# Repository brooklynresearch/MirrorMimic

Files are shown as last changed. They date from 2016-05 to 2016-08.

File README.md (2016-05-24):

# Mirror Mimic

This repository is for communicating and controlling robotic systems.
Currently set up for controlling torso, neck, and upper arm articulation.

## Software
1. [Arduino 1.6.8](https://www.arduino.cc)
2. [Teensyduino](https://www.pjrc.com/teensy/teensyduino.html)

### Software Libraries/Dependencies
1. DynamixelController - Controlling Dynamixels with the Teensy (Based on Arbotix Library)
2. [OSC - OSC communication with the Teensy](https://github.com/CNMAT/OSC)

## Hardware
1. [Microcontroller - Teensy 3.2](https://www.pjrc.com/store/teensy32.html)
2. [Servo - Dynamixel MX-64T](http://www.trossenrobotics.com/p/mx-64t-dynamixel-robot-actuator.aspx)
3. [Stepper Motor NEMA23 - 23L310S-LW8](http://www.anaheimautomation.com/products/stepper/stepper-motor-item.php?sID=20&pt=i&tID=75&cID=19)
4. [Stepper Driver - MBC25081TB](http://www.anaheimautomation.com/products/stepper/stepper-driver-item.php?sID=56&serID=4&pt=i&tID=87&cID=20)

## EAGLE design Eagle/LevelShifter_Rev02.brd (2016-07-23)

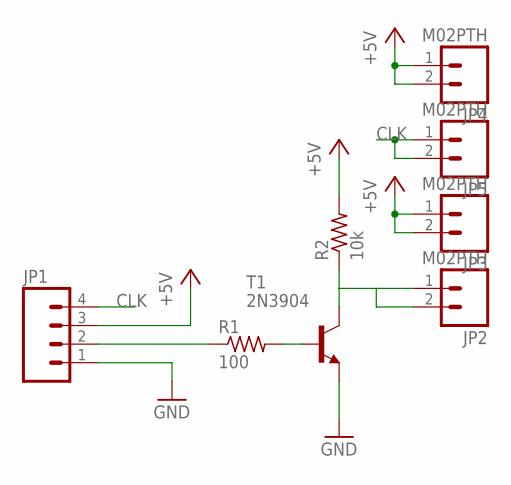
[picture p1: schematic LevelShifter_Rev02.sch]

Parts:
JP1: M04SCREW; SCREWTERMINAL-3.5MM-4
JP2, JP3, JP4, JP5: M02PTH; 1X02
R1: 100; 0204/7
R2: 10k; 0204/7
T1: 2N3904; TO92

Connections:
+5V: JP1.3, JP3.1, JP3.2, JP4.1, JP4.2, R2.2
CLK: JP1.4, JP5.1, JP5.2
GND: JP1.1, T1.3 (E)
unnamed: R1.2, T1.2 (B)
unnamed: JP2.1, JP2.2, R2.1, T1.1 (C)
unnamed: JP1.2, R1.1

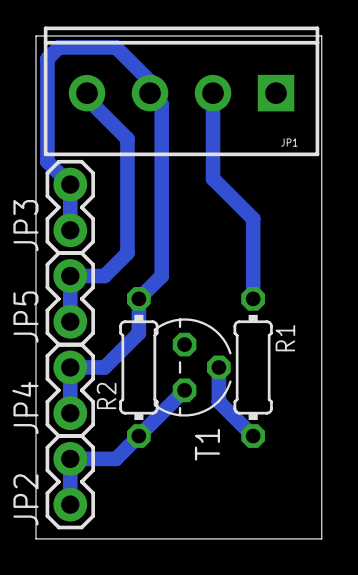
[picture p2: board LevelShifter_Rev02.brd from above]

Board: 2 copper layers, 15.9 x 27.9 mm, 8 parts (0 on the bottom side), 6 nets.

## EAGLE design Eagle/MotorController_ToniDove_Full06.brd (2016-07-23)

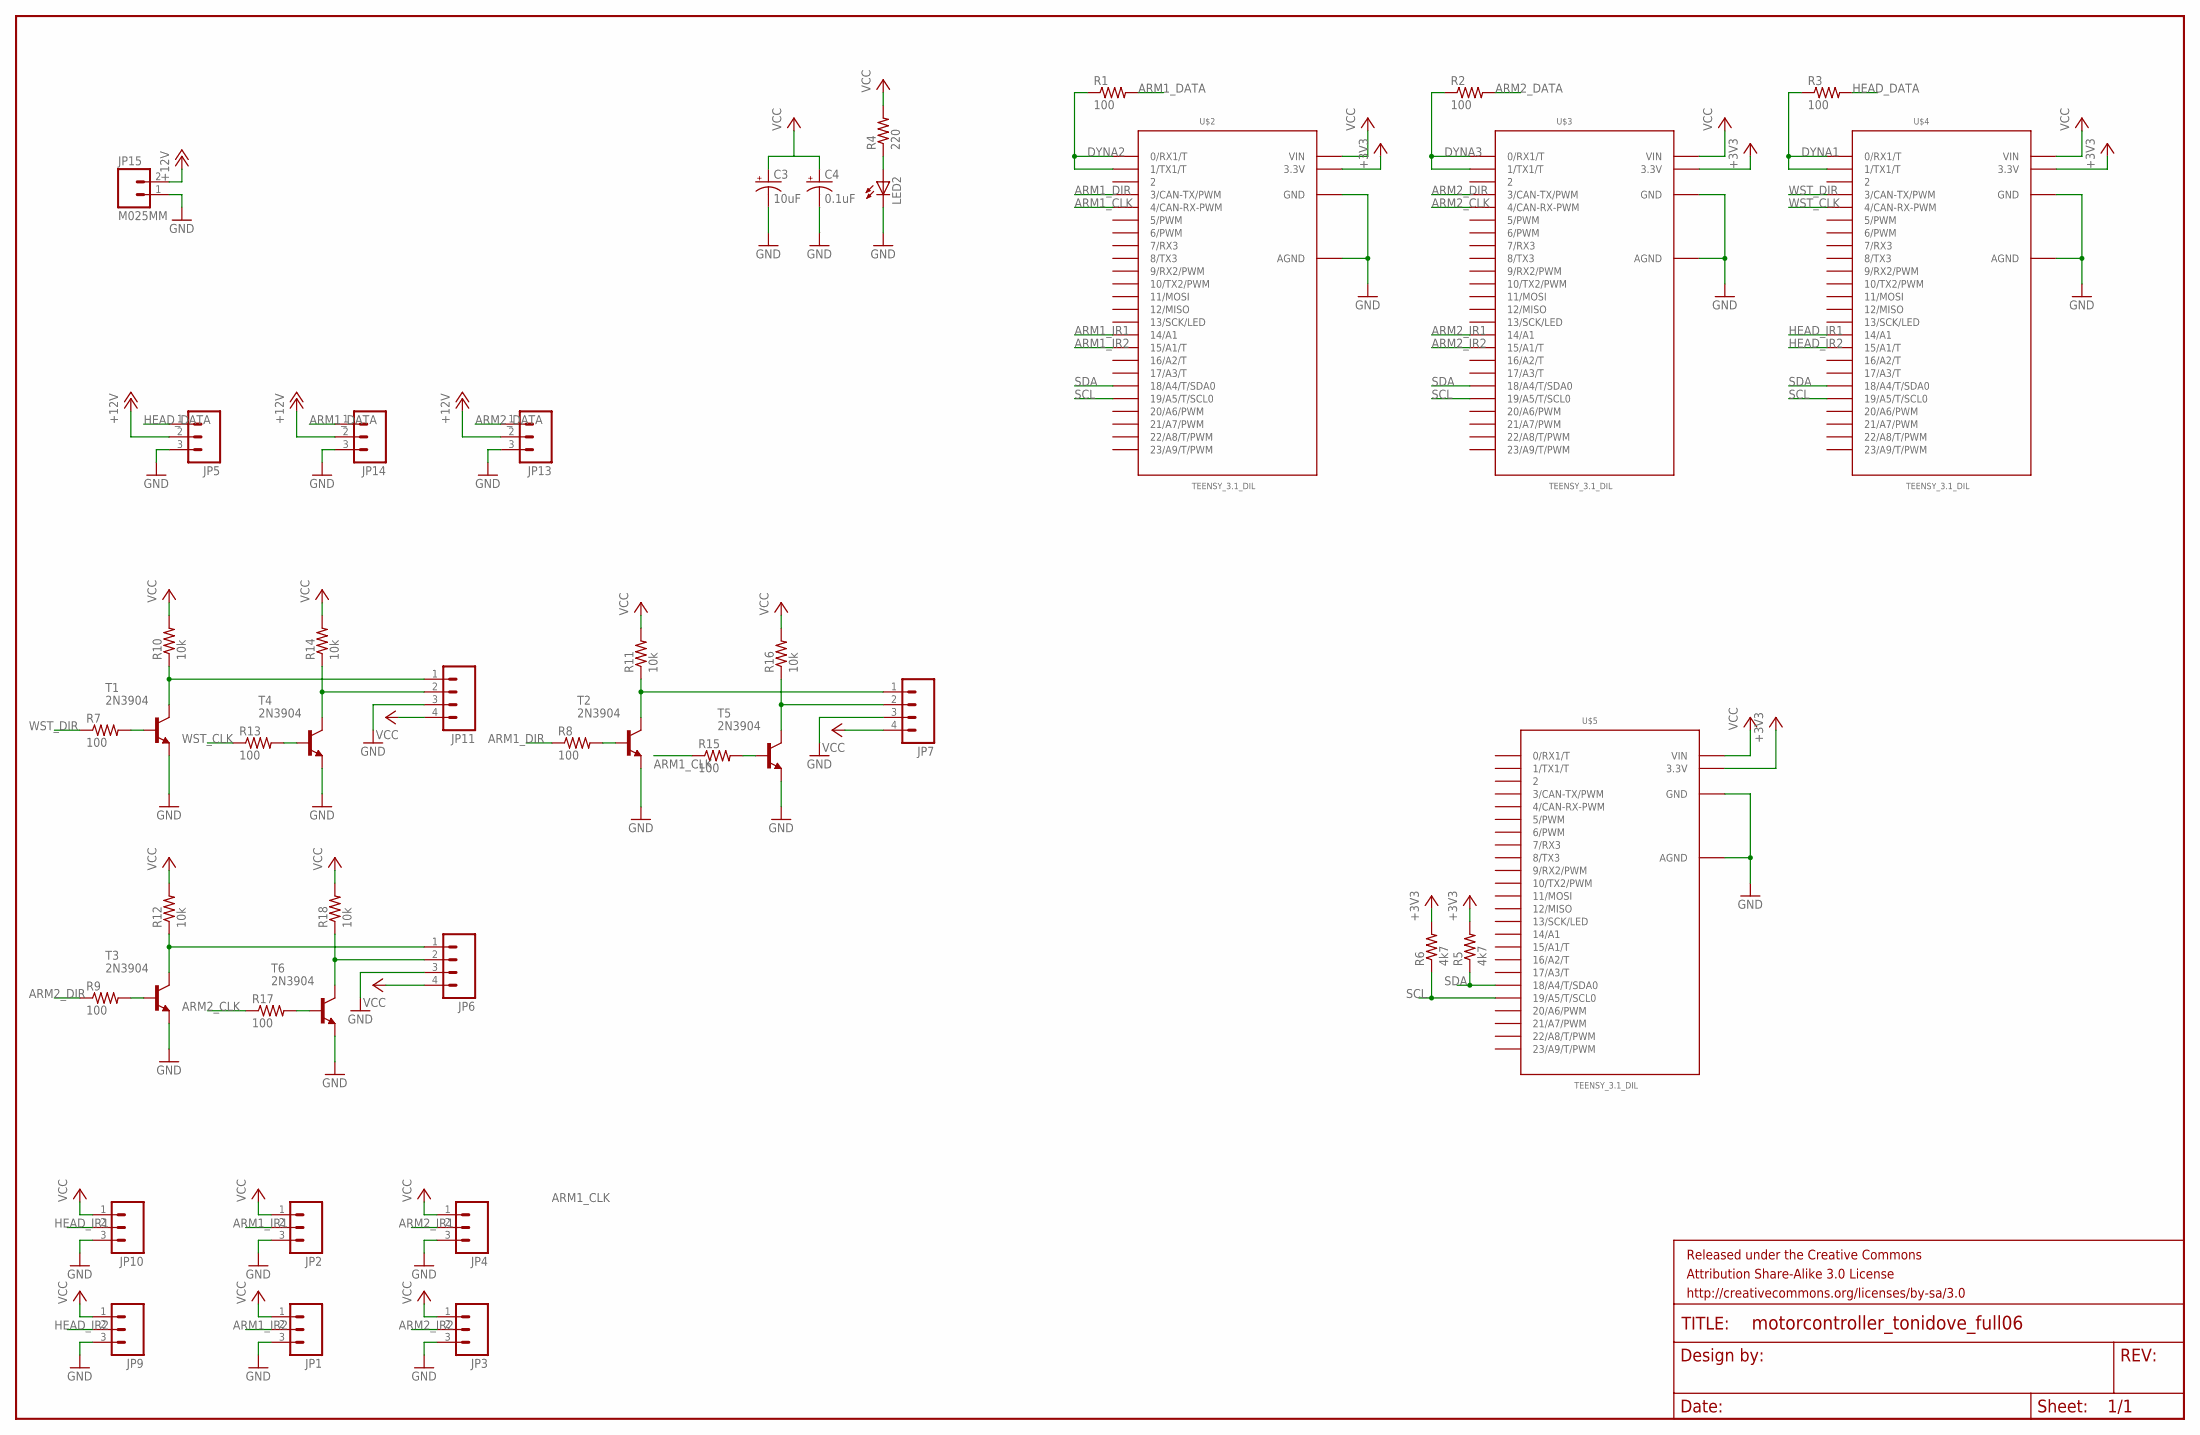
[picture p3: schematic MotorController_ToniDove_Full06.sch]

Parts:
C3: 10uF; E2,5-6E
C4: 0.1uF; E2,5-6E
FRAME1: FRAME-LEDGER; CREATIVE_COMMONS
JP1, JP2, JP3, JP4, JP5, JP9, JP10, JP13, JP14: M03PTH; 1X03
JP6, JP7, JP11: M04SCREW; SCREWTERMINAL-3.5MM-4
JP15: M025MM; SCREWTERMINAL-5MM-2
LED2: LED5MM
R1, R2, R3, R7, R8, R9, R13, R15, R17: 100; 0204/7
R4: 220; 0204/7
R5, R6: 4k7; 0204/7
R10, R11, R12, R14, R16, R18: 10k; 0204/7
T1, T2, T3, T4, T5, T6: 2N3904; TO92
U$2, U$3, U$4, U$5: TEENSY_3.1_DIL; TEENSY3-DIL

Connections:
+3V3: R5.2, R6.2, U$2.3.3V, U$3.3.3V, U$4.3.3V, U$5.3.3V
+12V: JP5.2, JP13.2, JP14.2, JP15.2
ARM1_CLK: R15.1, U$2.4 (4/CAN-RX-PWM)
ARM1_DATA: JP14.1, R1.2
ARM1_DIR: R8.1, U$2.3 (3/CAN-TX/PWM)
ARM1_IR1: JP2.2, U$2.14/A0 (14/A1)
ARM1_IR2: JP1.2, U$2.15/A1 (15/A1/T)
ARM2_CLK: R17.1, U$3.4 (4/CAN-RX-PWM)
ARM2_DATA: JP13.1, R2.2
ARM2_DIR: R9.1, U$3.3 (3/CAN-TX/PWM)
ARM2_IR1: JP4.2, U$3.14/A0 (14/A1)
ARM2_IR2: JP3.2, U$3.15/A1 (15/A1/T)
DYNA1: R3.1, U$4.0 (0/RX1/T), U$4.1 (1/TX1/T)
DYNA2: R1.1, U$2.0 (0/RX1/T), U$2.1 (1/TX1/T)
DYNA3: R2.1, U$3.0 (0/RX1/T), U$3.1 (1/TX1/T)
GND: C3.-, C4.-, JP1.3, JP2.3, JP3.3, JP4.3, JP5.3, JP6.3, JP7.3, JP9.3, JP10.3, JP11.3, JP13.3, JP14.3, JP15.1, LED2.K (C), T1.3 (E), T2.3 (E), T3.3 (E), T4.3 (E), T5.3 (E), T6.3 (E), U$2.AGND, U$2.GND, U$3.AGND, U$3.GND, U$4.AGND, U$4.GND, U$5.AGND, U$5.GND
HEAD_DATA: JP5.1, R3.2
HEAD_IR1: JP10.2, U$4.14/A0 (14/A1)
HEAD_IR2: JP9.2, U$4.15/A1 (15/A1/T)
unnamed: LED2.A, R4.1
unnamed: R13.2, T4.2 (B)
unnamed: R7.2, T1.2 (B)
unnamed: R8.2, T2.2 (B)
unnamed: R9.2, T3.2 (B)
unnamed: JP11.1, R10.1, T1.1 (C)
unnamed: JP7.1, R11.1, T2.1 (C)
unnamed: JP6.1, R12.1, T3.1 (C)
unnamed: JP11.2, R14.1, T4.1 (C)
unnamed: R15.2, T5.2 (B)
unnamed: JP7.2, R16.1, T5.1 (C)
unnamed: R17.2, T6.2 (B)
unnamed: JP6.2, R18.1, T6.1 (C)
SCL: R6.1, U$2.19/A5 (19/A5/T/SCL0), U$3.19/A5 (19/A5/T/SCL0), U$4.19/A5 (19/A5/T/SCL0), U$5.19/A5 (19/A5/T/SCL0)
SDA: R5.1, U$2.18/A4 (18/A4/T/SDA0), U$3.18/A4 (18/A4/T/SDA0), U$4.18/A4 (18/A4/T/SDA0), U$5.18/A4 (18/A4/T/SDA0)
VCC: C3.+, C4.+, JP1.1, JP2.1, JP3.1, JP4.1, JP6.4, JP7.4, JP9.1, JP10.1, JP11.4, R4.2, R10.2, R11.2, R12.2, R14.2, R16.2, R18.2, U$2.VIN, U$3.VIN, U$4.VIN, U$5.VIN
WST_CLK: R13.1, U$4.4 (4/CAN-RX-PWM)
WST_DIR: R7.1, U$4.3 (3/CAN-TX/PWM)

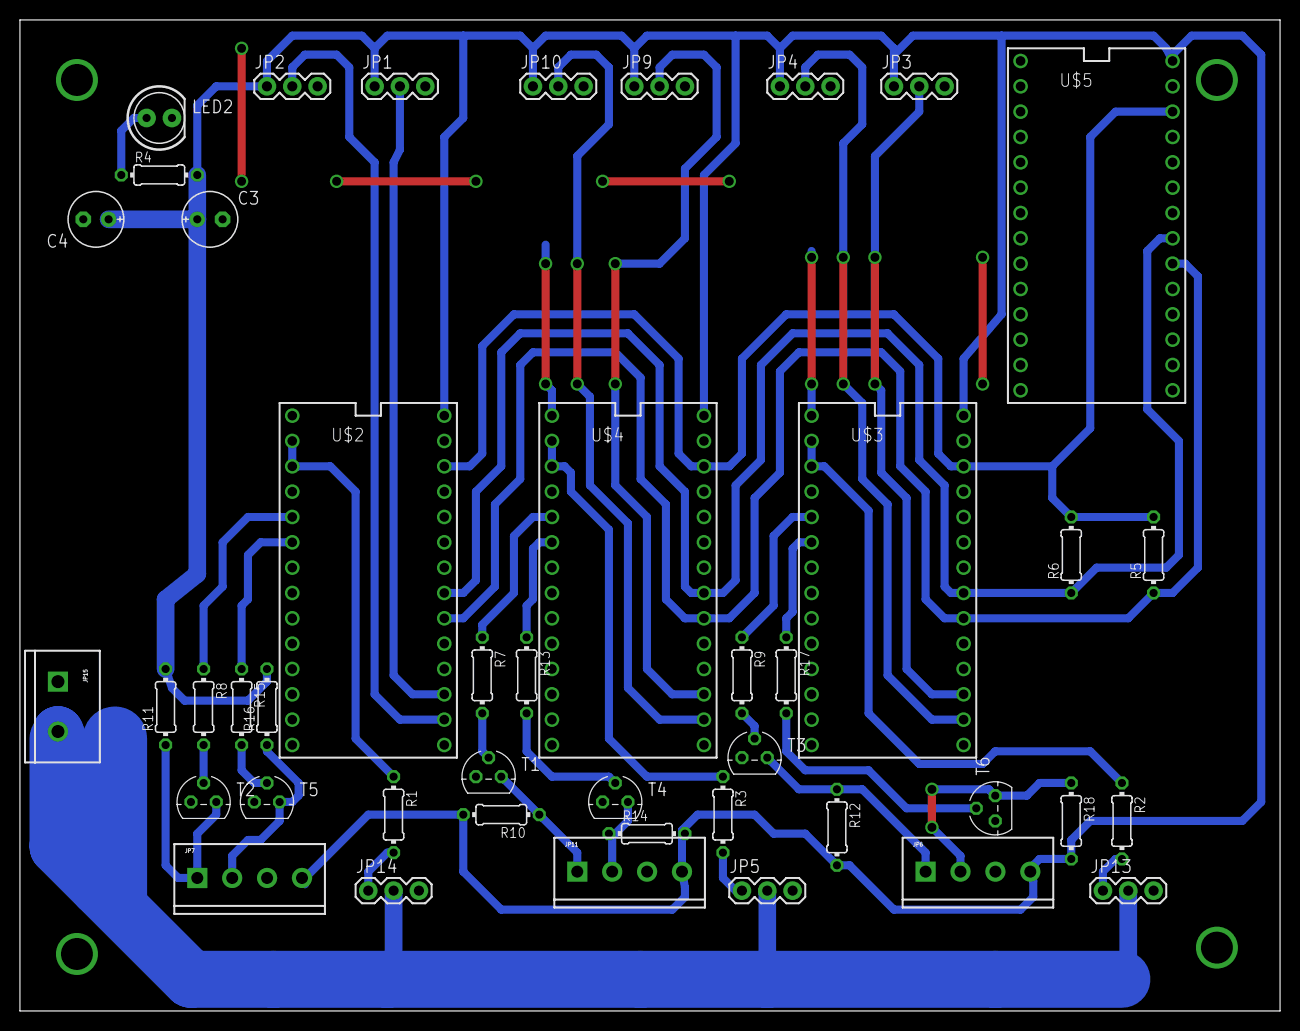
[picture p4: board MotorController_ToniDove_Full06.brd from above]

Board: 2 copper layers, 126.3 x 99.4 mm, 45 parts (0 on the bottom side), 37 nets.

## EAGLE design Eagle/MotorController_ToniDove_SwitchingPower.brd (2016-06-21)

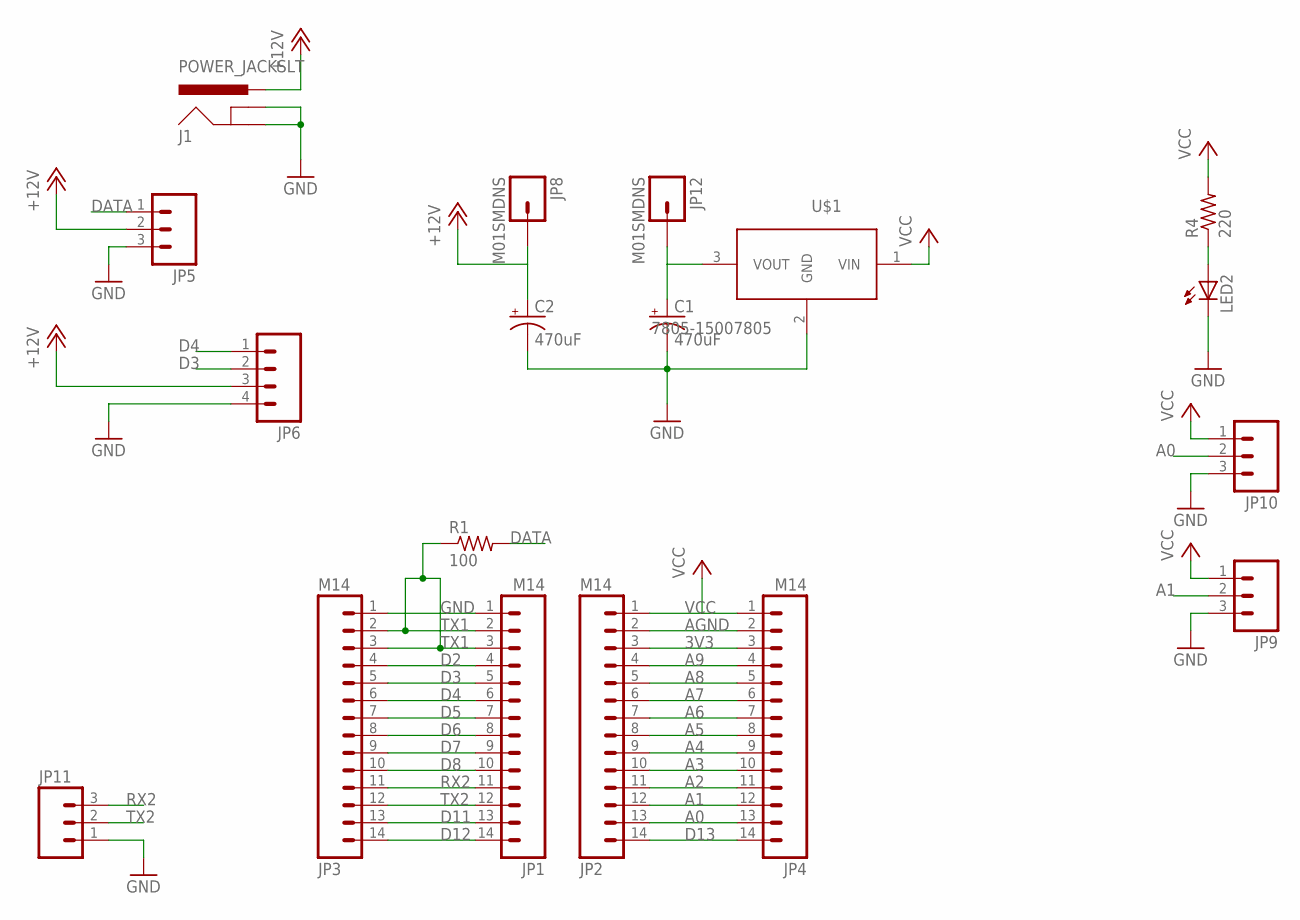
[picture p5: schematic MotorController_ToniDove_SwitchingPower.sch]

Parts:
C1, C2: 470uF; E5-13
J1: POWER_JACKSLT; POWER_JACK_SLOT
JP1, JP2, JP3, JP4: M14; 1X14
JP5, JP9, JP10, JP11: M03PTH; 1X03
JP6: M04PTH; 1X04
JP8, JP12: M01SMDNS; 1X01NS
LED2: LED5MM
R1: 100; 0204/7
R4: 220; 0204/7
U$1: 7805-15007805; UL94-V0

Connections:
3V3: JP2.3, JP4.3
+12V: C2.+, J1.PWR, JP5.2, JP6.3, JP8.1
A0: JP2.13, JP4.13, JP10.2
A1: JP2.12, JP4.12, JP9.2
A2: JP2.11, JP4.11
A3: JP2.10, JP4.10
A4: JP2.9, JP4.9
A5: JP2.8, JP4.8
A6: JP2.7, JP4.7
A7: JP2.6, JP4.6
A8: JP2.5, JP4.5
A9: JP2.4, JP4.4
AGND: JP2.2, JP4.2
D2: JP1.4, JP3.4
D3: JP1.5, JP3.5, JP6.2
D4: JP1.6, JP3.6, JP6.1
D5: JP1.7, JP3.7
D6: JP1.8, JP3.8
D7: JP1.9, JP3.9
D8: JP1.10, JP3.10
D11: JP1.13, JP3.13
D12: JP1.14, JP3.14
D13: JP2.14, JP4.14
DATA: JP5.1, R1.2
GND: C1.-, C2.-, J1.GND@1 (GNDBREAK), J1.GND@2 (GND), JP1.1, JP3.1, JP5.3, JP6.4, JP9.3, JP10.3, JP11.1, LED2.K (C), U$1.2 (GND)
unnamed: LED2.A, R4.1
unnamed: C1.+, JP12.1, U$1.3 (VOUT)
RX2: JP1.11, JP3.11, JP11.3
TX1: JP1.2, JP1.3, JP3.2, JP3.3, R1.1
TX2: JP1.12, JP3.12, JP11.2
VCC: JP2.1, JP4.1, JP9.1, JP10.1, R4.2, U$1.1 (VIN)

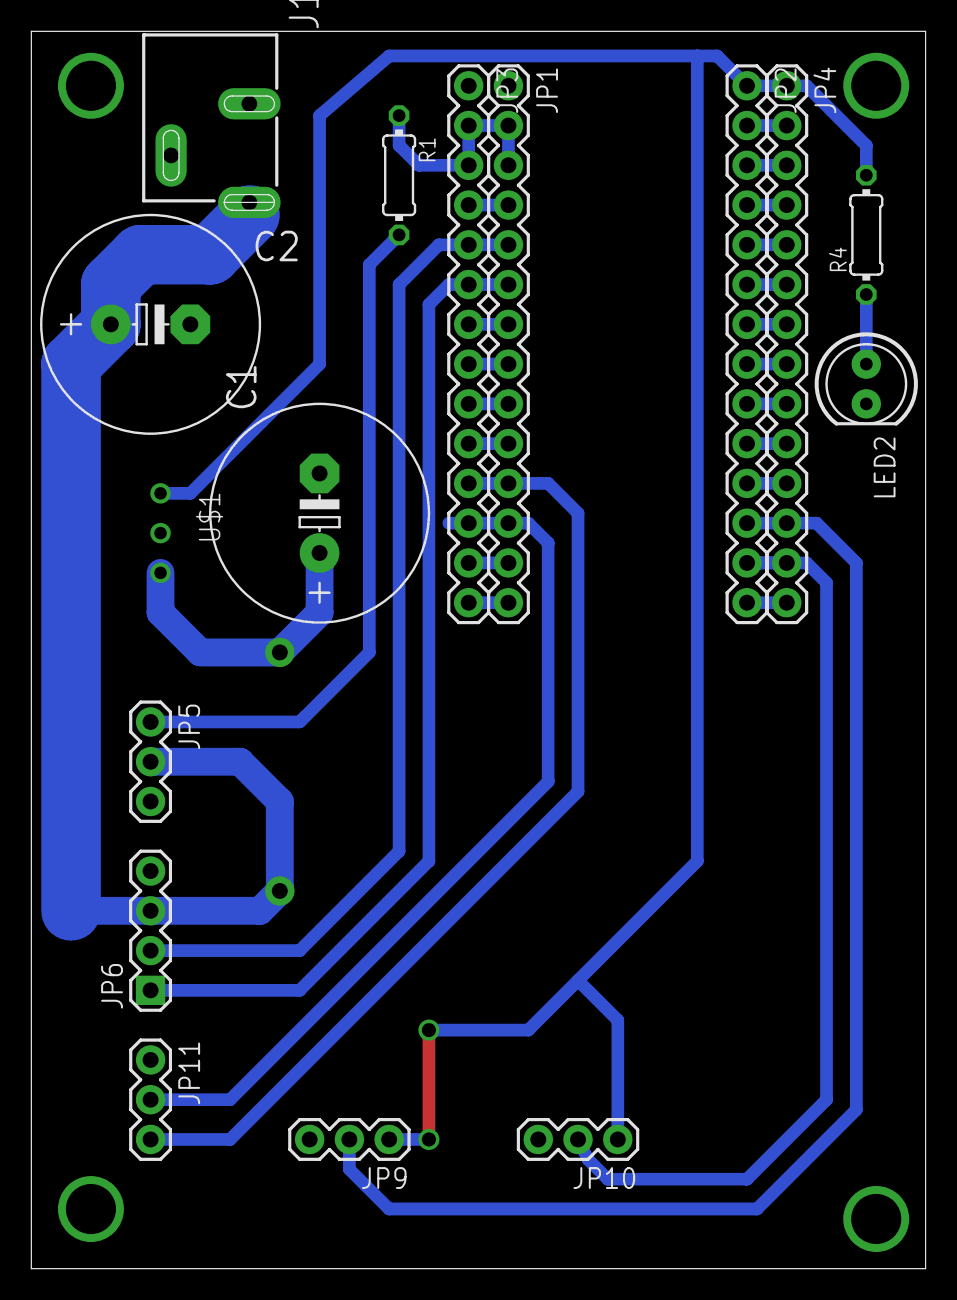
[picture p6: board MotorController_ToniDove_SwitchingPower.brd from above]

Board: 2 copper layers, 57.1 x 79.0 mm, 18 parts (0 on the bottom side), 31 nets.

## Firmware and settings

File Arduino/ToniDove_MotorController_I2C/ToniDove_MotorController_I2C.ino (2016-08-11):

#include <ax12Controller.h>
#include <DynamixelController.h>
#include <Wire.h>


//====================================================================================================
// Motor Controller Defines 
//====================================================================================================
// Define HALF_ARM, FULL_ARM, or NECK to setup up configuration and amount of servos and steppers.

//#define HALF_ARM
#define FULL_ARM
//#define NECK

#ifdef HALF_ARM
#define SHOULDER_L  1
#define SHOULDER_R  2
#define SHOULDER_R_START 1100
#define NUM_SERVOS   2
String CONTROLLERNAME = "RIGHT ARM";
#define I2CADDRESS 8
#define UPWARDS 0
#define DOWNWARDS 1
#endif

#ifdef FULL_ARM
#define SHOULDER_L  1
#define SHOULDER_R  2
#define SHOULDER_R_START 990
#define ELBOW_R     3
#define ELBOW_R_START 0
#define ELBOW_P     4
#define ELBOW_P_START 3400
#define NUM_SERVOS   4
String CONTROLLERNAME = "LEFT ARM";
#define I2CADDRESS 7
#define UPWARDS 0
#define DOWNWARDS 1
#endif

#ifdef NECK
#define NECK_R      1
#define NECK_P      2
#define NUM_SERVOS   2
String CONTROLLERNAME = "NECK AND WAIST";
#define I2CADDRESS 6
#define UPWARDS 1
#define DOWNWARDS 0
#endif

#define MASTER_ADDRESS    5

int servoID[NUM_SERVOS] = {
#ifdef HALF_ARM
  SHOULDER_L, SHOULDER_R
#endif
#ifdef FULL_ARM
  SHOULDER_L, SHOULDER_R, ELBOW_R, ELBOW_P
#endif
#ifdef NECK
  NECK_R, NECK_P
#endif
};

//====================================================================================================
// Dynamixel Setup
//====================================================================================================
DynamixelController dynaControl = DynamixelController();  // Initialize the Dynamixel Controller
#define MAX_TORQUE 1023

//====================================================================================================
// Serial Callback Command Setup
//====================================================================================================
#define I2CCOMMANDDEBUG        // Debug Mode. Use this define statement for Serial Print out readings.
//#define SERIALCOMMAND Serial2     // Which UART will we be sending/receiving commands from

#define I2CCOMMANDBUFFER 256   // Buffer size of the command Serial port
#define MAXI2CCOMMANDS  10     // 
#define MAXDELIMETER 2
//#define SERIALBAUDRATE 115200

char inChar;                              // A character read from the serial stream 
char charBuffer[I2CCOMMANDBUFFER];   // Buffer of stored characters while waiting for terminator character
int  bufPos;                              // Current position in the buffer
char delim[MAXDELIMETER];                 // null-terminated list of character to be used as delimeters for tokenizing (default " ")
char terminator = '\r';                   // Character that signals end of command (default '\r')
char *token;                              // Returned token from the command buffer as returned by strtok_r
char *last;                               // State variable used by strtok_r during processing
typedef struct _callback {
  char i2cCommand[I2CCOMMANDBUFFER];
  void (*function)();
} I2CCommandCallback;            // Data structure to hold Command/Handler function key-value pairs
int numCommand;
I2CCommandCallback CommandList[MAXI2CCOMMANDS];   // Actual definition for command/handler array
void (*defaultHandler)();   


//====================================================================================================
// Stepper Motor Setup
//====================================================================================================
#define TOTALSTEPS 3150
#ifdef FULL_ARM
#define HOMEPOS 200
#endif
#ifdef HALF_ARM
#define HOMEPOS 2500
#endif
#ifdef NECK
#define HOMEPOS 1024
#endif

int dirpin = 3;
int steppin = 4;

int sensorPin0 = A0;    // select the input pin for the potentiometer
int sensorPin1 = A1;
int sensorValue = 0;  // variable to store the value coming from the sensor
int limitThreshold = 100;
int curPosition = 0;
int prevPosition = curPosition;
bool firstTime = true;

#ifdef HALF_ARM
int stepperPosition = 0;
#endif

#ifdef FULL_ARM
int stepperPosition = 0;
#endif

#ifdef NECK
int stepperPosition = 0;
#endif

int newPosition = HOMEPOS;
unsigned long stepperTime = 0;

#ifdef HALF_ARM
unsigned int stepperInterval = 300;
#endif

#ifdef FULL_ARM
unsigned int stepperInterval = 300;
#endif

#ifdef NECK
unsigned int stepperInterval = 300;
#endif

int stepDirection = UPWARDS;

int defaultSpeed  =   100;

void setup() {
  
  Serial.begin(9600);  // debug serial port
  
  //Set the direction Pin to -1 for half duplex control on the Teensy 
  dynaControl.begin(1000000, &Serial1, -1, NUM_SERVOS);
  
  
  strncpy(delim," ",MAXDELIMETER);  // strtok_r needs a null-terminated string
  numCommand=0;    // Number of callback handlers installed
  clearI2CBuffer();

//  addI2CCommand("HELLO", SayHello);
//  addI2CCommand("TEST",  serialMotorTest);
  
  #ifdef NECK
  addI2CCommand("H_ROT", rotateHead);
  addI2CCommand("H_PIV", pivotHead);
  addI2CCommand("HRPOS", getHeadRotatePos);
  addI2CCommand("HPPOS", getHeadPivotPos);
  addI2CCommand("H_RST", resetHead);
  addI2CCommand("W_ROT", rotateWaist);
  addI2CCommand("W_POS", getWaistPos);
  #else
  addI2CCommand("S_ROT", rotateShoulder);
  addI2CCommand("S_PIV", pivotShoulder);
  addI2CCommand("SRPOS", getShoulderRotatePos);
  addI2CCommand("SPPOS", getShoulderPivotPos);
  addI2CCommand("S_RST", resetShoulder);
  #endif

  #ifdef FULL_ARM
  addI2CCommand("E_ROT", rotateElbow);
  addI2CCommand("E_PIV", pivotElbow);
  addI2CCommand("ERPOS", getElbowRotatePos);
  addI2CCommand("EPPOS", getElbowPivotPos);
  addI2CCommand("E_RST", resetElbow);
  #endif
  
  addI2CCommand("A_POS", getAllMotorPositions);
  addDefaultHandler(unrecognized);

  Wire.begin(I2CADDRESS);                // join i2c bus with address #8
  Wire.onReceive(receiveEvent); // register event
  Wire.onRequest(respondEvent); // callback event

  pinMode(dirpin, OUTPUT);
  pinMode(steppin, OUTPUT);

  delay(1000);

  Serial.println(F("====================================================================="));
  Serial.print(F("TONI DOVE :: "));Serial.print(CONTROLLERNAME);Serial.println(" CONTROLLER");
  Serial.println(F("====================================================================="));

  //serialMotorTest();
  #ifdef NECK
  stepperPosition = HOMEPOS;
  curPosition = HOMEPOS;  
  Serial.print("Stepper Position: ");Serial.println(stepperPosition);
  #else
  findHome();
  #endif
  delay(1000);
  
  for(int i=0; i<NUM_SERVOS; i++){
      dynaControl.resetServoTorqueLimit(servoID[i], MAX_TORQUE);
      dynaControl.setServoSpeed(servoID[i], defaultSpeed);
      Serial.print("SERVO ");Serial.print(servoID[i]);
      Serial.print("\t\tVOLTAGE: ");Serial.print(((float)dynaControl.getServoVoltage(servoID[i])/10));
      Serial.print("\tTEMP: ");Serial.print(dynaControl.getServoTemp(servoID[i]));
      Serial.print("\tPOS: ");Serial.print(dynaControl.getServoPosition(servoID[i]));
      Serial.print("\tSPEED: ");Serial.print(dynaControl.getServoSpeed(servoID[i]));
      Serial.print("\t\tMAX ANGLES: ");
      int *p;
      p = dynaControl.getAngleLimits(servoID[i]);
        for(int j=0; j<2; j++){
          Serial.print(*(p + j));Serial.print("  ");
        }
      Serial.println();
  }
}

void loop()
{
  //readSerialCommand();
  moveStepperToPosition(newPosition);
}

void findHome(){
  #ifdef FULL_ARM
    dynaControl.setServoPosition(SHOULDER_R, SHOULDER_R_START);
    dynaControl.setServoPosition(ELBOW_R, ELBOW_R_START);
    dynaControl.setServoPosition(ELBOW_P, ELBOW_P_START);
  #endif
  #ifdef HALF_ARM
    dynaControl.setServoPosition(SHOULDER_R, SHOULDER_R_START);
  #endif
  
  if(checkSensor(sensorPin0) || checkSensor(sensorPin1)){
    
    digitalWrite(dirpin, HIGH);
    Serial.println("Looking For First Limit");
    
    while(checkSensor(sensorPin0)){
      digitalWrite(steppin, LOW);
      digitalWrite(steppin, HIGH);
      delay(1);
    }
    delay(1000);
    int stepCount = 0;
    digitalWrite(dirpin, LOW);

    Serial.println("Looking For Second Limit");
    
    while(checkSensor(sensorPin1)){
      digitalWrite(steppin, LOW);
      digitalWrite(steppin, HIGH);
      stepCount++;
      stepperPosition++;
      delay(1);
    }
    Serial.print("Total Step Count: ");Serial.println(stepCount);
    delay(1000);
    //digitalWrite(dirpin,LOW);
    
    while(moveStepperToPosition(HOMEPOS));

    curPosition = HOMEPOS;
    
    Serial.print("Stepper Position: ");Serial.println(stepperPosition);
  } else {
    Serial.println("You're stepper motor is out of bounds.");
    Serial.println("Please turn off power.");
    Serial.println("Check sensors and/or reset stepper motors to a proper position.");
  }
}

bool checkSensor(int sensorPin){
  bool sensorState = 0;
  
  if(analogRead(sensorPin) < limitThreshold){
    sensorState = 1;
  } else {
    sensorState = 0;
  }
  
  return sensorState;
}


#ifdef NECK
void rotateHead(){
  char *arg;  
  arg = nextArgument();    // Get the next argument from the SerialCommand object buffer
  if (arg != NULL)      // As long as it existed, take it
  {
    int newPos = atoi(arg);
    #ifdef I2CCOMMANDDEBUG
    Serial.print("Head rotating to: "); 
    Serial.println(arg); 
    #endif
    dynaControl.setServoPosition(NECK_R, newPos);
  } 
  else {
    Serial.println("No position supplied.  Please enter a number between 0 - 2048"); 
  }
}

void pivotHead(){
  char *arg;  
  arg = nextArgument();    // Get the next argument from the SerialCommand object buffer
  if (arg != NULL)      // As long as it existed, take it
  {
    int newPos = atoi(arg);
    #ifdef I2CCOMMANDDEBUG
    Serial.print("Head pivoting to: "); 
    Serial.println(arg); 
    #endif
    dynaControl.setServoPosition(NECK_P, newPos);
  } 
  else {
    Serial.println("No position supplied.  Please enter a number between 0 - 2048"); 
  }
}

void getHeadRotatePos(){
  curPosition = dynaControl.getServoPosition(NECK_R);
  #ifdef I2CCOMMANDDEBUG
    Serial.print("SHOULDER PIVOT POS: ");
    Serial.println(curPosition);
  #endif
}

void getHeadPivotPos(){
  curPosition = dynaControl.getServoPosition(NECK_P);
  #ifdef I2CCOMMANDDEBUG
    Serial.print("SHOULDER PIVOT POS: ");
    Serial.println(curPosition);
  #endif
}

void rotateWaist(){
  char *arg;  
  arg = nextArgument();    // Get the next argument from the SerialCommand object buffer
  if (arg != NULL)      // As long as it existed, take it
  {
    newPosition = atoi(arg);
    #ifdef I2CCOMMANDDEBUG
    Serial.print("Waist rotating to: "); 
    Serial.println(arg); 
    #endif
  } 
  else {
    Serial.println("No position supplied.  Please enter a number between 0 - 3150"); 
  }
}

void getWaistPos(){
  curPosition = stepperPosition;
  #ifdef I2CCOMMANDDEBUG
    Serial.print("SHOULDER ROTATE POS: ");
    Serial.println(curPosition);
  #endif
}

void resetHead(){
  for(int i=0; i<NUM_SERVOS; i++){
      dynaControl.resetServoTorqueLimit(servoID[i], MAX_TORQUE);
  }
}

#else

void rotateShoulder(){
  char *arg;  
  arg = nextArgument();    // Get the next argument from the SerialCommand object buffer
  if (arg != NULL)      // As long as it existed, take it
  {
    newPosition = atoi(arg);
    #ifdef I2CCOMMANDDEBUG
    Serial.print("Shoulder rotating to: "); 
    Serial.println(arg); 
    #endif
  } 
  else {
    Serial.println("No position supplied.  Please enter a number between 0 - 3150"); 
  }
}

void pivotShoulder(){
  char *arg;  
  arg = nextArgument();    // Get the next argument from the SerialCommand object buffer
  if (arg != NULL)      // As long as it existed, take it
  {
    int newPos = atoi(arg);
    #ifdef I2CCOMMANDDEBUG
    Serial.print("Shoulder pivoting to: "); 
    Serial.println(arg); 
    #endif
    dynaControl.setDualServoPosition(SHOULDER_L, SHOULDER_R, newPos);
  } 
  else {
    Serial.println("No position supplied.  Please enter a number between 0 - 2048"); 
  }
}

void getShoulderRotatePos(){
  curPosition = stepperPosition;
  #ifdef I2CCOMMANDDEBUG
    Serial.print("SHOULDER ROTATE POS: ");
    Serial.println(curPosition);
  #endif
}

void getShoulderPivotPos(){
  curPosition = dynaControl.getServoPosition(SHOULDER_L);
  #ifdef I2CCOMMANDDEBUG
    Serial.print("SHOULDER PIVOT POS: ");
    Serial.println(curPosition);
  #endif
}

void resetShoulder(){
//  for(int i=0; i<2; i++){
//      dynaControl.resetServoTorqueLimit(servoID[i], MAX_TORQUE);
//  }
  dynaControl.resetServoTorqueLimit(SHOULDER_L, MAX_TORQUE);
  dynaControl.resetServoTorqueLimit(SHOULDER_R, MAX_TORQUE);
}
#endif

#ifdef FULL_ARM
void rotateElbow(){
  char *arg;  
  arg = nextArgument();    // Get the next argument from the SerialCommand object buffer
  if (arg != NULL)      // As long as it existed, take it
  {
    int newPos = atoi(arg);
    #ifdef I2CCOMMANDDEBUG
    Serial.print("Elbow rotating to: "); 
    Serial.println(arg); 
    #endif
    dynaControl.setServoPosition(ELBOW_R, newPos);
  } 
  else {
    Serial.println("No position supplied.  Please enter a number between 0 - 2048"); 
  }
}

void pivotElbow(){
  char *arg;  
  arg = nextArgument();    // Get the next argument from the SerialCommand object buffer
  if (arg != NULL)      // As long as it existed, take it
  {
    int newPos = atoi(arg);
    #ifdef I2CCOMMANDDEBUG
    Serial.print("Elbow Pivoting to: "); 
    Serial.println(arg); 
    #endif
    dynaControl.setServoPosition(ELBOW_P, newPos);
  } 
  else {
    Serial.println("No position supplied.  Please enter a number between 0 - 2048"); 
  }
}

void getElbowRotatePos(){
  curPosition = dynaControl.getServoPosition(ELBOW_R);
  #ifdef I2CCOMMANDDEBUG
    Serial.print("ELBOW ROTATE POS: ");
    Serial.println(curPosition);
  #endif
}

void getElbowPivotPos(){
  curPosition = dynaControl.getServoPosition(ELBOW_P);
  #ifdef I2CCOMMANDDEBUG
    Serial.print("ELBOW PIVOT POS: ");
    Serial.println(curPosition);
  #endif
}

void resetElbow(){
  for(int i=2; i<NUM_SERVOS; i++){
      dynaControl.resetServoTorqueLimit(servoID[i], MAX_TORQUE);
  }
}
#endif

/* TO DO:
 *  SET THIS UP FOR I2C CALLBACK
 */
void getAllMotorPositions(){  
  Serial.print(getShoulderPosition());
  for(int i=0; i<NUM_SERVOS; i++){
    Serial.print(", ");
    Serial.print(dynaControl.getServoPosition(servoID[i]));
  }
  #ifdef HALF_ARM
  Serial.println();
  #else
  Serial.print(", ");
  #endif
}

int getShoulderPosition(){
  return stepperPosition;
}

int moveStepperToPosition(int targetPos){

  targetPos = checkTargetPositionLimit(targetPos);

  int differenceOfSteps = (abs)(stepperPosition - targetPos);
  int addStep;
  
  if(stepperPosition < targetPos){
    digitalWrite(dirpin, UPWARDS);
    stepDirection = UPWARDS;
    addStep = 1;
  } else {
    digitalWrite(dirpin, DOWNWARDS);
    stepDirection = DOWNWARDS;
    addStep = -1;
  }

  if(differenceOfSteps){

    /*
    #ifdef I2CCOMMANDDEBUG
      Serial.print("Stepper moving to: "); 
      Serial.print(targetPos); 
      Serial.print(" in ");
      Serial.print(differenceOfSteps);
      Serial.print(" steps in the Direction of: ");
      Serial.println(stepDirection);
    #endif
    */
    
    //if(checkLimitSwitches(stepDirection)){
      if((micros() - stepperTime) > stepperInterval){
        pulseStepper();
        stepperPosition += addStep;
        stepperTime = micros();
      }
    //}
  }
  
  return differenceOfSteps;
}

int checkTargetPositionLimit(int tarPos){
  if(tarPos > TOTALSTEPS){
    tarPos = TOTALSTEPS;
  } else if(tarPos < 0){
    tarPos = 0;
  }

  return tarPos;
}

bool checkLimitSwitches(int stepperDir){
  bool sensorVal0, sensorVal1, stepperState;
  sensorVal0 = checkSensor(sensorPin0);
  sensorVal1 = checkSensor(sensorPin1);
  if(!sensorVal0){
    if(stepperDir == UPWARDS){
      stepperState = true;
    } else {
      stepperState = false;
    }
  } else if(!sensorVal1){
    if(stepperDir == DOWNWARDS){
      stepperState = true;
    } else {
      stepperState = false;
    }
  } else {
    stepperState = true;
  }
  
  return stepperState;
}

void pulseStepper(){
  digitalWrite(steppin, LOW);
  digitalWrite(steppin, HIGH);
}


void serialMotorTest()
{
  int i;

  digitalWrite(dirpin, LOW);     // Set the direction.

  #ifdef I2CCOMMANDDEBUG
  Serial.println("Moving Forward");
  #endif
  for (i = 0; i<1000; i++)       // Iterate for 4000 microsteps.
  {
    digitalWrite(steppin, LOW);  // This LOW to HIGH change is what creates the
    digitalWrite(steppin, HIGH); // "Rising Edge" so the easydriver knows to when to step.
    delayMicroseconds(200);      // This delay time is close to top speed for this
  }                              // particular motor. Any faster the motor stalls.

  digitalWrite(dirpin, HIGH);    // Change direction.
  delay(2000);

  #ifdef I2CCOMMANDDEBUG
  Serial.println("Moving Backward");
  #endif
  
  for (i = 0; i<1000; i++)       // Iterate for 4000 microsteps
  {
    digitalWrite(steppin, LOW);  // This LOW to HIGH change is what creates the
    digitalWrite(steppin, HIGH); // "Rising Edge" so the easydriver knows to when to step.
    delayMicroseconds(200);      // This delay time is close to top speed for this
  }      
  delay(2000);

}

void addI2CCommand(const char *command, void (*function)())
{
 if (numCommand < MAXI2CCOMMANDS) {
    #ifdef I2CCOMMANDDEBUG
    Serial.print(numCommand); 
    Serial.print("-"); 
    Serial.print("Adding command for "); 
    Serial.println(command); 
    #endif
    
    strncpy(CommandList[numCommand].i2cCommand,command,I2CCOMMANDBUFFER); 
    CommandList[numCommand].function = function; 
    numCommand++; 
  } else {
    // In this case, you tried to push more commands into the buffer than it is compiled to hold.  
    // Not much we can do since there is no real visible error assertion, we just ignore adding
    // the command
    #ifdef I2CCOMMANDDEBUG
    Serial.println("Too many handlers - recompile changing MAXSERIALCOMMANDS"); 
    #endif 
  }
}

void SayHello()
{
  char *arg;  
  arg = nextArgument();    // Get the next argument from the SerialCommand object buffer
  if (arg != NULL)      // As long as it existed, take it
  {
    Serial.print("Hello "); 
    Serial.println(arg); 
  } 
  else {
    Serial.println("Hello, whoever you are"); 
  }
}
void respondEvent(){
  byte posBuffer[2];

  posBuffer[0] = curPosition >> 8;
  posBuffer[1] = curPosition & 255;
  Wire.write(posBuffer, 2);

  #ifdef I2CCOMMANDDEBUG
  Serial.print(posBuffer[0]);
  Serial.println(posBuffer[1]);
  #endif
}
void receiveEvent(int howMany) 
{
 // If we're using the Hardware port, check it.   Otherwise check the user-created SoftwareSerial Port
  while (Wire.available() > 0) 
  {
    int i; 
    boolean matched; 
    inChar = Wire.read();   // Read single available character, there may be more waiting
    #ifdef I2CCOMMANDDEBUG
    Serial.print(inChar);   // Echo back to serial stream
    #endif
    if (inChar == terminator) {     // Check for the terminator (default '\r') meaning end of command
      #ifdef I2CCOMMANDDEBUG
      Serial.print("Received: "); 
      Serial.println(charBuffer);
       #endif
      bufPos=0;           // Reset to start of buffer
      token = strtok_r(charBuffer,delim,&last);   // Search for command at start of buffer
      if (token == NULL) return; 
      matched=false; 
      for (i=0; i<numCommand; i++) {
        #ifdef I2CCOMMANDDEBUG
        Serial.print("Comparing ["); 
        Serial.print(token); 
        Serial.print("] to [");
        Serial.print(CommandList[i].i2cCommand);
        Serial.println("]");
        #endif
        // Compare the found command against the list of known commands for a match
        if (strncmp(token,CommandList[i].i2cCommand,I2CCOMMANDBUFFER) == 0) 
        {
          #ifdef I2CCOMMANDDEBUG
          Serial.print("Matched Command: "); 
          Serial.println(token);
          #endif
          // Execute the stored handler function for the command
          (*CommandList[i].function)(); 
          clearI2CBuffer(); 
          matched=true; 
          break; 
        }
      }
      if (matched==false) {
        (*defaultHandler)(); 
        clearI2CBuffer(); 
      }

    }
    if (isprint(inChar))   // Only printable characters into the buffer
    {
      charBuffer[bufPos++]=inChar;   // Put character into buffer
      charBuffer[bufPos]='\0';  // Null terminate
      if (bufPos > I2CCOMMANDBUFFER-1) bufPos=0; // wrap buffer around if full  
    }
  }
}

char *nextArgument() 
{
 char *nextToken;
  nextToken = strtok_r(NULL, delim, &last); 
  return nextToken; 
}

void clearI2CBuffer()
{
  for (int i=0; i<I2CCOMMANDBUFFER; i++) 
  {
    charBuffer[i]='\0';
  }
  bufPos=0; 
}

void addDefaultHandler(void (*function)())
{
  defaultHandler = function;
}

void unrecognized(){
  Serial.println("Sorry bro, not sure what you're trying to do here");
}

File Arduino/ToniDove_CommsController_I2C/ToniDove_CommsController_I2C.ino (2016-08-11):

// UDP / OSC comms to serial comms for use with DynamixelController_Teensy.ino

#include <Ethernet.h>
#include <EthernetUdp.h>
#include <SPI.h>    
#include <OSCBundle.h>
#include <OSCBoards.h>
#include <Wire.h>

#define DEBUG        

#define I2C_ADDRESS     5

#define HEAD_ADDRESS    6
#define LEFT_ADDRESS    7
#define RIGHT_ADDRESS   8   


int motorCommAddress[3] = {HEAD_ADDRESS, LEFT_ADDRESS, RIGHT_ADDRESS};
int i2cAddress = 0;
#define POS_BYTES 20
//String motorAddress;

EthernetUDP Udp;

//the Arduino's IP
IPAddress ip(192, 168, 8, 123);
IPAddress outIp(192, 168, 8, 105);

//port numbers
const unsigned int inPort = 12345;
const unsigned int outPort = 12346;

//everything on the network needs a unique MAC 
#if defined(__MK20DX128__)
// Teensy 3 has MAC burned in
static byte mac[6];

void read(uint8_t word, uint8_t *mac, uint8_t offset) {
  FTFL_FCCOB0 = 0x41;             // Selects the READONCE command
  FTFL_FCCOB1 = word;             // read the given word of read once area

  // launch command and wait until complete
  FTFL_FSTAT = FTFL_FSTAT_CCIF;
  while(!(FTFL_FSTAT & FTFL_FSTAT_CCIF));

  *(mac+offset) =   FTFL_FCCOB5;       // collect only the top three bytes,
  *(mac+offset+1) = FTFL_FCCOB6;       // in the right orientation (big endian).
  *(mac+offset+2) = FTFL_FCCOB7;       // Skip FTFL_FCCOB4 as it's always 0.
}
void read_mac() {
  read(0xe,mac,0);
  read(0xf,mac,3);
}

#else
void read_mac() {}
 byte mac[] = {  
  0xDE, 0xAD, 0xBE, 0xEF, 0xFE, 0xED }; // you can find this written on the board of some Arduino Ethernets or shields
#endif

//outgoing messages
OSCBundle bundleOUT;

//converts the pin to an osc address
char * numToOSCAddress( int pin){
    static char s[10];
    int i = 9;
  
    s[i--]= '\0';
  do
    {
    s[i] = "0123456789"[pin % 10];
                --i;
                pin /= 10;
    }
    while(pin && i);
    s[i] = '/';
    return &s[i];
}

void setup() {
      // some local debug -- we can see this in serial port
  Serial.begin(9600);
  Wire.begin();
  
  read_mac();
  Ethernet.begin(mac,ip);
  Udp.begin(inPort);

  delay(1000);

  Serial.println(F("====================================================================="));
  Serial.println(F("TONI DOVE :: OSC TO I2C"));
  Serial.println(F("====================================================================="));

  #ifdef DEBUG
  OSCMessage msg("/hello");
  msg.add("world!");
  Udp.beginPacket(outIp, outPort);
  msg.send(Udp);
  Udp.endPacket();
  msg.empty();
  #endif
}

void loop(){ 
  
   OSCMessage newMes;
   int size;
 
   if( (size = Udp.parsePacket())>0)
   {
         //Serial.println("Received Packet");
//         unsigned int outPort = Udp.remotePort();

         while(size--)
           newMes.fill(Udp.read());

        if(!newMes.hasError())
        {
            newMes.route("/move", routePositionMessage);
            newMes.route("/get", routeGetMessage);
            newMes.route("/reset", routeResetMessage);
        }     
    }
}

void routeGetMessage(OSCMessage &msg, int addrOffset){
      int pinMatched;
      String motorAddress;
      
      //Test OSC Routing
      pinMatched = msg.match("/test", addrOffset);
      if(pinMatched){
        Serial.println("OSC \"/get\" Comms Functional");
      }

      pinMatched = msg.match("/allPos", addrOffset);
      if(pinMatched){
        getAllPositions();
      }
      
      pinMatched = msg.match("/head", addrOffset);
      if(pinMatched){
        i2cAddress = HEAD_ADDRESS;
        if (msg.fullMatch("/rotate", pinMatched+addrOffset)){
          motorAddress = "HRPOS";
        } else if (msg.fullMatch("/pivot", pinMatched+addrOffset)){
          motorAddress = "HPPOS";
        }
      }
      
      pinMatched = msg.match("/waist", addrOffset);
      if(pinMatched){
        i2cAddress = HEAD_ADDRESS;
        if (msg.fullMatch("/rotate", pinMatched+addrOffset)){
          motorAddress = "W_POS";
        } else if (msg.fullMatch("/pivot", pinMatched+addrOffset)){
          motorAddress = "W_POS";
        }
      }

      pinMatched = msg.match("/left", addrOffset);
      if(pinMatched){
        i2cAddress = LEFT_ADDRESS;
        if (msg.fullMatch("/shoulder/rotate", pinMatched+addrOffset)){
          motorAddress = "SRPOS";
        } else if (msg.fullMatch("/shoulder/pivot", pinMatched+addrOffset)){
          motorAddress = "SPPOS";
        } else if (msg.fullMatch("/elbow/rotate", pinMatched+addrOffset)){
          motorAddress = "ERPOS";
        } else if (msg.fullMatch("/elbow/pivot", pinMatched+addrOffset)){
          motorAddress = "EPPOS";
        }
      }

      pinMatched = msg.match("/right", addrOffset);
      if(pinMatched){
        i2cAddress = RIGHT_ADDRESS;
        if (msg.fullMatch("/shoulder/rotate", pinMatched+addrOffset)){
          motorAddress = "SRPOS";
        } else if (msg.fullMatch("/shoulder/pivot", pinMatched+addrOffset)){
          motorAddress = "SPPOS";
        } 
      }
    
      // DEBUG message for what route was sent
      #ifdef DEBUG
      Serial.print("Message Sent: ");Serial.println(motorAddress);
      #endif
      getPosition(msg, addrOffset, i2cAddress, motorAddress);

      #ifdef DEBUG
      Serial.print("Message Sent: ");Serial.println(motorAddress);
      #endif
      
}
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

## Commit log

2016-05-23 Uploaded Initial Teensy/Arduino Code
    Code to control Dynamixels with Teensy.
    Serial Comms, Limiters, and Feedback functions still need to be
    implemented.
2016-05-24 Streamlined Dynamixel Library
    Streamlined Dynamixel Library and added an example sketch that should
    work with Teensy 3.2 right off the bat.
2016-05-24 Serial Comms included
    Updated Arduino Code.
    Serial Comms included, Read Me updated, and incorporated new Dynamixel
    Library.
2016-05-25 OSC to serial prototype
    May need to heavily rewrite this so as to not be clunky once we have
    anything in.
    Currently just takes in OSC and has a basic commented out structure for
    how we might possibly route things. Does not currently relay serial
2016-06-09 Dynamixel Callbacks Added
    Added Callback for get AngleLimits getting Max Torque, and
    incorporating a new begin function that passes the Max Servo amount.
2016-06-09 Added Stepper Motor Control
    Added Stepper Motor Control via Serial. Need to merge Dynamixel and
    Steppermotor code into one.
2016-06-10 Consolidated Stepper and Servo Code
    Consolidated Stepper and Servo Code and added positioning commands for
    all the Servos. Need to add get commands for all positioning, torque,
    voltage, speed, etc.
2016-06-21 OSCSerial updated
    Added functionality to OSCSerial.
    Still need to send feedback of sensors and positions of motors.
    [MotorController_ToniDove_Full.brd, MotorController_ToniDove_Full.sch, MotorController_ToniDove_SwitchingPower.brd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]
2016-06-21 Minor Changes for Compiling and Checking
    OSC Serial compiles and Motor Controller lets the USB Serial know which
    address it is currently assigned to.
2016-06-22 Position Feedback
    Added Initial Position Feedback Code for both OSCSerial and Motor
    Controller code. Still needs to be fully tested.
2016-07-23 I2C Arduino Sketches And Max Tester
    Uploaded the newest Arduino sketch for Comms and Motor controller for
    the torso. Plus uploaded a basic Max Tester to test comms.
    [LevelShifter_Rev02.brd, LevelShifter_Rev02.sch, MotorController_ToniDove_Full04.brd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]
2016-08-11 Initial Push for Position Feedback
    Updated Max and Arduino sketches to get positional feedback from the
    stepper motors and servos.

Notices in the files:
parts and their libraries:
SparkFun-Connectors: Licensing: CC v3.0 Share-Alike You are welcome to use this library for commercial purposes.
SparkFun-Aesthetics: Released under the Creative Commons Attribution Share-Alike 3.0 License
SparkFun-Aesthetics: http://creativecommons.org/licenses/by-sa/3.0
